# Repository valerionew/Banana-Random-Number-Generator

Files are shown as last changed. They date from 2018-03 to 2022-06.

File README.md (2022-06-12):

# Banana Random Number Generator
  


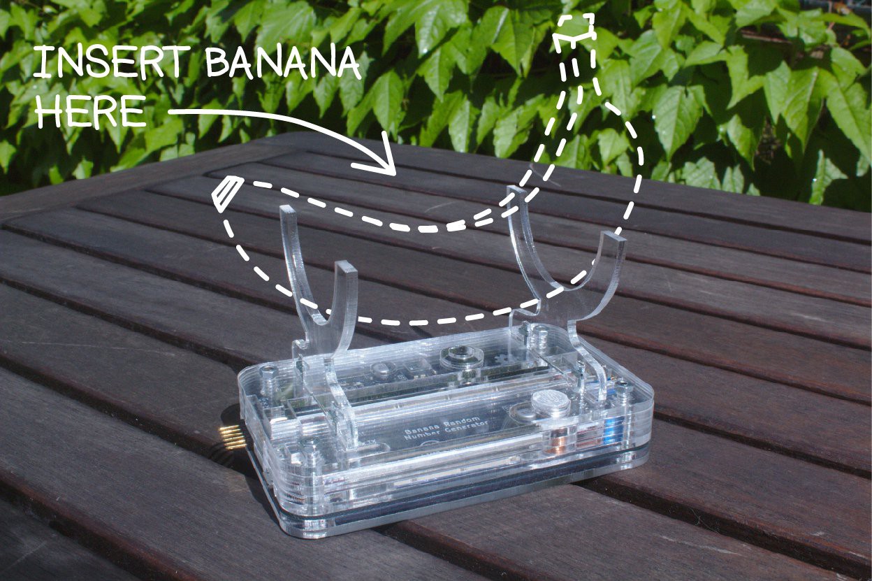
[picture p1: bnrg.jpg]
brng


## Project description 
An Arduino based true random number generator. Takes it's peculiar name from the potassium-40 present in bananas, used as radiation source for the random number generatation.  
  
_Disclaimer: the radioactivity from the bananas doesn't quite make the difference, the background radiation is more than enough to make the generator work. Potassium is definitely detected, some tests conducted with pure KCl and KOH showed a huge increase in the detector activity._

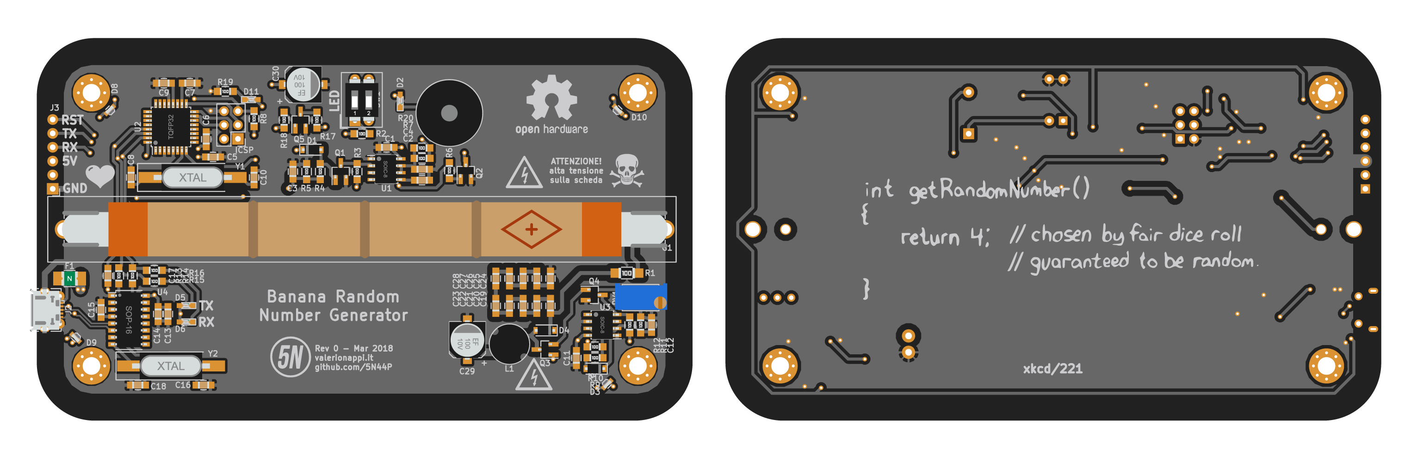
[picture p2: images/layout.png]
layout 1


1. [Project status](#project-status)  
1. [Hardware](#hardware)  
1. [Software](#software) 
1. [Enclosure](#enclosure) 

## Project status 
The current release is fully working. 
## Hardware 
The hardware is based around the popular ATMega328P and the STS-5 (a.k.a. CTC-5) Geiger-Müller tube.
## Software

As of this moment there are available two versions of the firmware:
- **minimal_test.c**: this version is fully compatible with the unmodified hardware. It uses the hardware interrupt INT0 and has proven to be unreliable when brought into an arduino environment due to interferences with the millis() function from the Wiring core. On it's own works with no problems. [Read more on this, in italian](https://www.valerionappi.it/chi-quadro/)
- **minimal_test_with capture.c**: this version and has proven to be much more reliable than the previous, since it captures the timer stamp via dedicated hardware and it's not subject to software delays. It's based on the timer capture function on PB0/ICP1 pin of the ATMega. This version needs a bodge wire between pin PD2 and pin PB0, as shown below:  

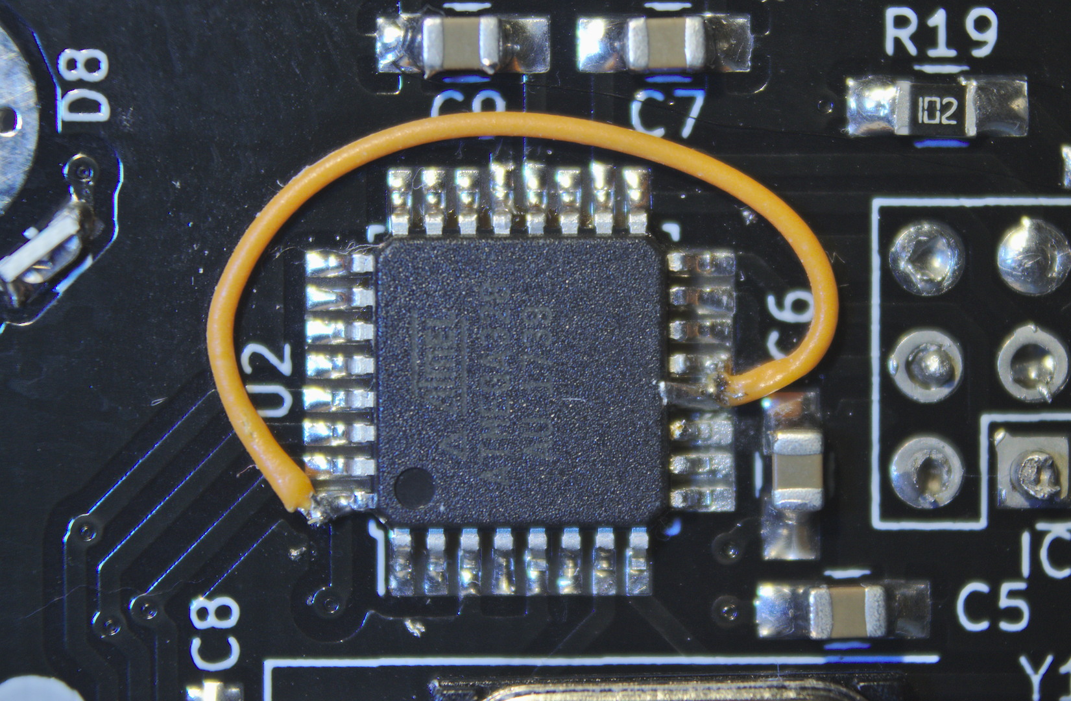
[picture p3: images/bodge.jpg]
mod


I'm currently working on an arduino version on the software, that will be published in this repo as soon as it gives consistent results.
In the future another version of the firmware which makes use of the hardware as a plain Geiger counter might be developed. Any help is welcome!
## Enclosure
The board is designed to fit in a laser cut acrylic enclosure to protect the user from the high voltage present onboard. 
The enclosure design files are included and licensed under [CC-BY-SA 4.0 license](http://creativecommons.org/licenses/by-sa/4.0/)

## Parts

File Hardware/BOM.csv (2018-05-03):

Id | Ref | Package | Qty | Value
1 | BZ1 | Buzzer_12x9.5RM7.6 | 1 | Buzzer
5 | C11 C1 C4 C5 C6 C13 C14 C15 C17 C19 C20 C21 C22 C23 C24 C25 C26 C27 C28 C2 C7 C3 C9 C31 | C_0805_HandSoldering | 24 | 100n 50V
35 | C29 C30 | CP_Elec_6.3x5.3 | 2 | 100u 6V
11 | C8 C10 C16 C18 C12 | C_0805_HandSoldering | 5 | 22p 10V
14 | D2 D11 | LED_0603_HandSoldering | 2 | LL-S194PBC-B4-1B
15 | D1 D3 D4 | D_SOD-123 | 3 | USL1M
6 | D5 D6 | LED_0603_HandSoldering | 2 | LL-S192UAC-1A
37 | D7 D8 D9 D10 | 0802_side_led | 4 | OSR50802C1E
16 | F1 | R_1210_HandSoldering | 1 | Polyfuse 500mA
17 | G1 | Geiger | 1 | STS-20 geiger + 2 KEYSTONE 3518P
18 | ICSP | Pin_Header_Straight_2x03_Pitch2.54mm | 1 | ISP
19 | J2 | USB_Micro-B_Molex-105017-0001 | 1 | MOLEX 105017 0001
4 | J3 | Pin_Header_Angled_1x06_Pitch2.54mm | 1 | Angled connector
20 | L1 | L_Radial_D7.2mm_P3.00mm_MuRATA_1700 | 1 | 15mH FASTRON 11PHC-153K-50
21 | Q1 Q2 Q4 Q5 | SOT-23_Handsoldering | 4 | BC847
22 | Q3 | SOT-23_Handsoldering | 1 | MMBTA42
23 | R1 | R_1206_HandSoldering | 1 | 10M YAGEO RC1206JR-0710ML
7 | R15 R16 R10 R13 R14 R19 | R_0805_HandSoldering | 6 | 1k
24 | R2 R6 R9 R17 R18 | R_0805_HandSoldering | 5 | 220
26 | R4 R5 R12 R11 R7 R20 R3 R8 | R_0805_HandSoldering | 8 | 100k
29 | RV1 | Potentiometer_Trimmer_Vishay_T73XW_Vertical | 1 | 100
30 | SW1 | SW_DIP_x2_W7.62mm_Slide | 1 | DIPTRONICS NDI-02H-V
31 | U1 U3 | SOIC-8_3.9x4.9mm_Pitch1.27mm | 2 | LM555N
32 | U2 | TQFP-32_7x7mm_Pitch0.8mm | 1 | ATMEGA328P-AU
33 | U4 | SOP-16_4.4x10.4mm_Pitch1.27mm | 1 | CH340G
36 | Y1 | Crystal_SMD_HC49-SD_HandSoldering | 1 | 16MHz LF XTAL003237
34 | Y2 | Crystal_SMD_HC49-SD_HandSoldering | 1 | 12MHz LF XTAL003210

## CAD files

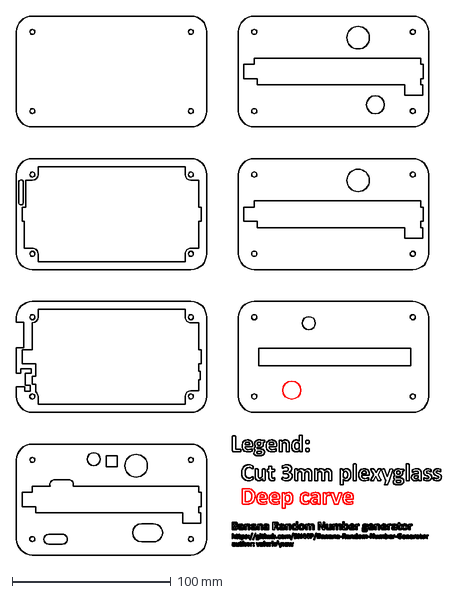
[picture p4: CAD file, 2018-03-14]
enclosure/enclosure.dxf
268.1 x 340.0 mm

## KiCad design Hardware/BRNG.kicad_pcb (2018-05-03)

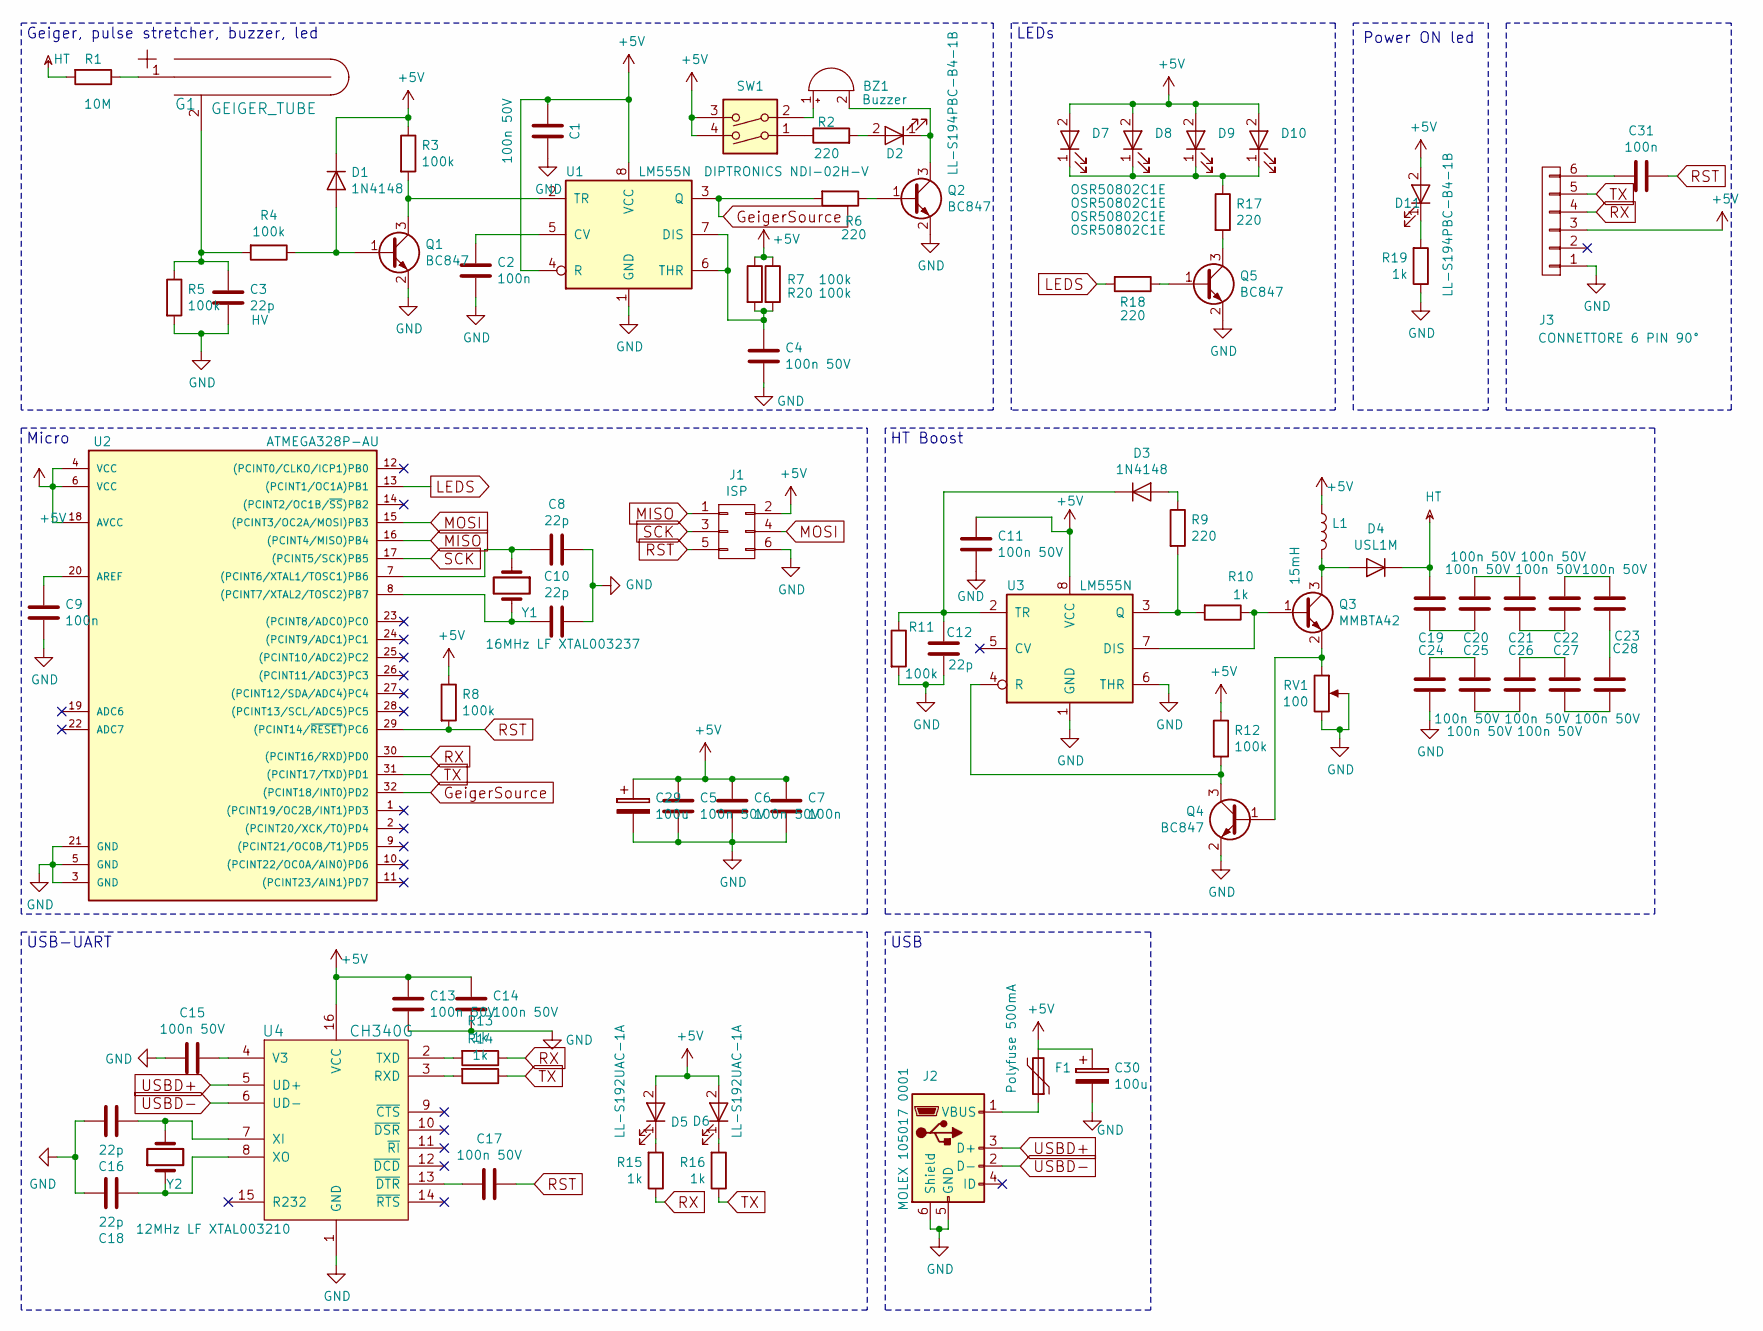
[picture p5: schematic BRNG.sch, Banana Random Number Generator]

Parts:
BZ1: Buzzer; Buzzer_12x9.5RM7.6
C1, C4, C5, C6, C11, C13, C14, C15, C17, C19, C20, C21, C22, C23, C24, C25, C26, C27, C28: 100n 50V; C_0805_HandSoldering
C2, C7, C9, C31: 100n; C_0805_HandSoldering
C3, C8, C10, C12, C16, C18: 22p; C_0805_HandSoldering
C29, C30: 100u; CP_Elec_6.3x5.3
D1, D3: 1N4148; D_SOD-123
D2, D11: LL-S194PBC-B4-1B; LED_0603_HandSoldering
D4: USL1M; D_SOD-123
D5, D6: LL-S192UAC-1A; LED_0603_HandSoldering
D7, D8, D9, D10: OSR50802C1E; 0802_side_led
F1: Polyfuse 500mA; R_1210_HandSoldering
G1: GEIGER_TUBE; Geiger
J1: ISP; Pin_Header_Straight_2x03_Pitch2.54mm
J2: MOLEX 105017 0001; USB_Micro-B_Molex-105017-0001
J3: CONNETTORE 6 PIN 90°; Pin_Header_Angled_1x06_Pitch2.54mm
L1: 15mH; L_Radial_D7.2mm_P3.00mm_MuRATA_1700
Q1, Q2, Q4, Q5: BC847; SOT-23_Handsoldering
Q3: MMBTA42; SOT-23_Handsoldering
R1: 10M; R_1206_HandSoldering
R2, R6, R9, R17, R18: 220; R_0805_HandSoldering
R3, R4, R5, R7, R8, R11, R12, R20: 100k; R_0805_HandSoldering
R10, R13, R14, R15, R16, R19: 1k; R_0805_HandSoldering
RV1: 100; Potentiometer_Trimmer_Vishay_T73XW_Vertical
SW1: DIPTRONICS NDI-02H-V; SW_DIP_x2_W7.62mm_Slide
U1, U3: LM555N; SOIC-8_3.9x4.9mm_Pitch1.27mm
U2: ATMEGA328P-AU; TQFP-32_7x7mm_Pitch0.8mm
U4: CH340G; SOP-16_4.4x10.4mm_Pitch1.27mm
Y1: 16MHz LF XTAL003237; Crystal_SMD_HC49-SD_HandSoldering
Y2: 12MHz LF XTAL003210; Crystal_SMD_HC49-SD_HandSoldering

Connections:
+5V: C1.2, C5.1, C6.1, C7.1, C11.1, C13.1, C14.1, C29.1, C30.1, D1.1 (K), D5.2 (A), D6.2 (A), D7.2 (A), D8.2 (A), D9.2 (A), D10.2 (A), D11.2 (A), F1.2, J1.2, J3.3, L1.1, R3.1, R7.1, R8.1, R12.1, R20.1, SW1.3, SW1.4, U1.4 (R), U1.8 (VCC), U2.4 (VCC), U2.6 (VCC), U2.18 (AVCC), U3.8 (VCC), U4.16 (VCC); also elsewhere on the board
GND: C1.1, C2.2, C3.2, C4.2, C5.2, C6.2, C7.2, C8.1, C9.2, C10.1, C11.2, C12.2, C13.2, C14.2, C15.2, C16.1, C18.1, C24.2, C29.2, C30.2, J1.6, J2.5 (GND), J2.6 (Shield), J3.1, Q1.2 (E), Q2.2 (E), Q4.2 (E), Q5.2 (E), R5.2, R11.2, R19.1, RV1.2, RV1.3, U1.1 (GND), U2.3 (GND), U2.5 (GND), U2.21 (GND), U3.1 (GND), U3.6 (THR), U4.1 (GND); also elsewhere on the board
GeigerSource: R6.2, U1.3 (Q), U2.32 ((PCINT18/INT0)PD2)
HT: C19.1, D4.1 (K), R1.2
LEDS: R18.2, U2.13 ((PCINT1/OC1A)PB1)
MISO: J1.1, U2.16 ((PCINT4/MISO)PB4); also elsewhere on the board
MOSI: J1.4, U2.15 ((PCINT3/OC2A/MOSI)PB3); also elsewhere on the board
unnamed: BZ1.1 (-), SW1.2
unnamed: BZ1.2 (+), D2.1 (K), Q2.3 (C)
unnamed: C2.1, U1.5 (CV)
unnamed: C3.1, G1.2, R4.2, R5.1
unnamed: C4.1, R7.2, R20.2, U1.6 (THR), U1.7 (DIS)
unnamed: C8.2, U2.7 ((PCINT6/XTAL1/TOSC1)PB6), Y1.1
unnamed: C9.1, U2.20 (AREF)
unnamed: C10.2, U2.8 ((PCINT7/XTAL2/TOSC2)PB7), Y1.2
unnamed: C12.1, D3.1 (K), R11.1, U3.2 (TR)
unnamed: C15.1, U4.4 (V3)
unnamed: C16.2, U4.7 (XI), Y2.2
unnamed: C17.2, U4.13 (~DTR)
unnamed: C18.2, U4.8 (XO), Y2.1
unnamed: C19.2, C20.2
unnamed: C20.1, C21.1
unnamed: C21.2, C22.2
unnamed: C22.1, C23.1
unnamed: C23.2, C28.1
unnamed: C24.1, C25.1
unnamed: C25.2, C26.2
unnamed: C26.1, C27.1
unnamed: C27.2, C28.2
unnamed: C31.1, J3.6
unnamed: D1.2 (A), Q1.1 (B), R4.1
unnamed: D2.2 (A), R2.2
unnamed: D3.2 (A), R9.1
unnamed: D4.2 (A), L1.2, Q3.3 (C)
unnamed: D5.1 (K), R15.2
unnamed: D6.1 (K), R16.2
unnamed: D7.1 (K), D8.1 (K), D9.1 (K), D10.1 (K), R17.1
unnamed: D11.1 (K), R19.2
unnamed: F1.1, J2.1 (VBUS)
unnamed: G1.1, R1.1
unnamed: Q1.3 (C), R3.2, U1.2 (TR)
unnamed: Q2.1 (B), R6.1
unnamed: Q3.1 (B), R10.1, U3.7 (DIS)
unnamed: Q3.2 (E), Q4.1 (B), RV1.1
unnamed: Q4.3 (C), R12.2, U3.4 (R)
unnamed: Q5.1 (B), R18.1
unnamed: Q5.3 (C), R17.2
unnamed: R2.1, SW1.1
unnamed: R9.2, R10.2, U3.3 (Q)
unnamed: R13.2, U4.2 (TXD)
unnamed: R14.2, U4.3 (RXD)
RST: C17.1, C31.2, J1.5, R8.2, U2.29 ((PCINT14/~RESET~)PC6); also elsewhere on the board
RX: J3.4, R13.1, R15.1, U2.30 ((PCINT16/RXD)PD0)
SCK: J1.3, U2.17 ((PCINT5/SCK)PB5); also elsewhere on the board
TX: J3.5, R14.1, R16.1, U2.31 ((PCINT17/TXD)PD1)
USBD+: J2.3 (D+), U4.5 (UD+)
USBD-: J2.2 (D-), U4.6 (UD-)

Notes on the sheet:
Micro
Geiger, pulse stretcher, buzzer, led
HT Boost
LEDs
Power ON led
USB-UART
USB

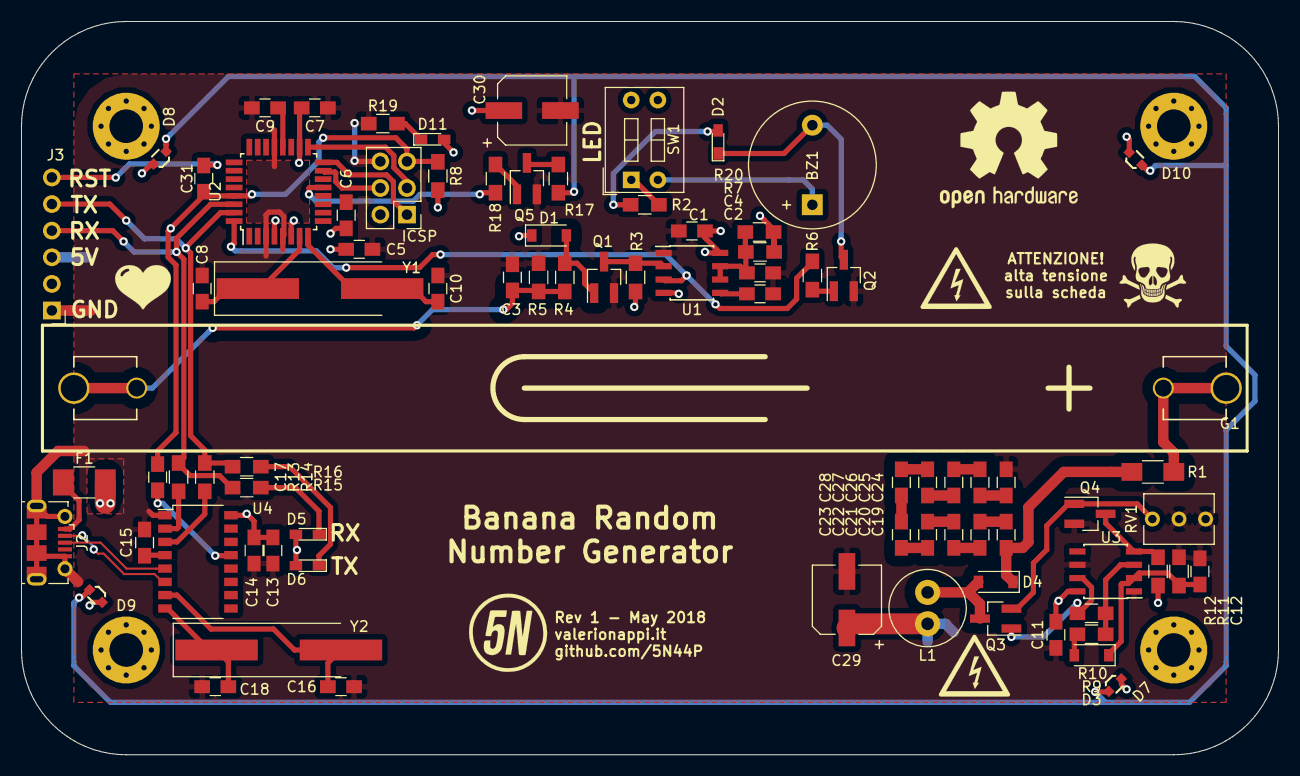
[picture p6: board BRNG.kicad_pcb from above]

Board: 2 copper layers, 120.0 x 70.0 mm, 82 parts (0 on the bottom side), 57 nets.

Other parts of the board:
ICSP: ISP; Pin_Header_Straight_2x03_Pitch2.54mm

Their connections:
+5V: ICSP.2; also elsewhere on the board
GND: ICSP.6; also elsewhere on the board
MISO: ICSP.1; also elsewhere on the board
MOSI: ICSP.4; also elsewhere on the board
RST: ICSP.5; also elsewhere on the board
SCK: ICSP.3; also elsewhere on the board

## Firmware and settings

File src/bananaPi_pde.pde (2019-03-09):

import processing.serial.*;

Serial bananaPort;  // Create object from Serial class

int x,y; // coordinates
float scalefactor;
String[] Serialports = Serial.list();
long inside, outside, total;

void setup() {
  
  if(Serialports.length > 0) // chech if there is at least one serial port
    bananaPort = new Serial(this, Serialports[0] , 9600); // choose the serial port of intrest, e.g. Serialports[1]
  printArray(Serial.list()); //print all serials, verify which number corresponds to yours
  
  // choose whatever resolution fits your screen.
  // it should be approximately 2x1 to display the interface correctly
  size(1500,750); 
  
  // scaling the 0-255 value from the serial into the appropriate format for the screen in use
  scalefactor = (height*0.7)/255;
 
   
  background(255); // white background
  colorMode(RGB,255); // RGB color mode
   
  // apply the transformation matrix for the point plot. 
  // remember that this function pushes a matrix, you have to pop it
  plotTransformation(); 
  
  strokeWeight(0.002); // set weak stroke weight
  ellipseMode(CENTER); // use center mode for the arcs
  fill(color(221, 254, 255)); // fill the shape with the right shade of blue
  arc(0,0,height*1.4,height*1.4,0,HALF_PI); // draw the circle quadrant
  
  noFill(); 
  strokeWeight(1); // heavier stroke
  rectMode(CORNER);
  rect(0,0,height*0.7,height*0.7); // draw the square
    
  noStroke(); // disable the stroke

  popMatrix(); // popping the plotTransformation() matrix
  
  
      fill(0); // black fill for the text
      textSize(width*0.05);
      text("Punti:", width*0.5, height*0.2); // total points label
      text("Interni:", width*0.5, height*0.35); // inside points label
      text("Esterni:", width*0.5, height*0.5); // outside points label
      textSize(width*0.075); // bigger text
      text("Pi:", width*0.5, height*0.8); // pi result label

  
}

void draw(){
  if (Serialports.length > 0){ // if there's at least one serial (not checking if it's assigned and initialized correctly, could be improved)
    
    if ( bananaPort.available() > 1) {  // if there's more than 1 byte available (we need two for each execution)
      x = bananaPort.read(); // first byte goes here
      y = bananaPort.read(); // second byte goes here
      total++; // increase total number
      plotTransformation(); // push transformation matrix for the plot
      if( x*x + y*y <= 255*255){ // if (x,y) belongs to a circle with raduis 255 the dot is inside
        fill(color(255,0,0));   // red dot
        inside++; // increase inside number
      }
      else{ // the point is outside the circle
        fill(color(0,0,255)); // blue dot
        outside++; // increase outside number
      }
      ellipse(x*scalefactor,y*scalefactor,5,5); // draw the dot, 5 pixel in size (not scalable, could be improved)
      popMatrix(); // pop the plot matrix
      
      println( x, y,inside,outside,total,(4.0*inside)/total); // DEBUG purpose only
      
      // blank the precedent values area
      fill(255); 
      rect(width*0.7,0,width*0.3,height);
      rect(width*0.6,height*0.65,width*0.4,height*0.35);
      
      // write the results since now
      fill(0);
      textSize(width*0.05);    
      text(int(total), width*0.7, height*0.2);
      text(int(inside), width*0.7, height*0.35);
      text(int(outside), width*0.7, height*0.5);
      textSize(width*0.075);
      text((4.0*inside)/total, width*0.6, height*0.8);
      
    }
  }
    
    
}

void plotTransformation(){
  pushMatrix(); // push a new matrix
  scale(1,-1); // invert Y axis
  translate(0,-height); // translate everything downwards
  translate(height*0.1,height*0.1); // give the plot a bit of margin
  // now point 0,0 is the origin of the plot
}

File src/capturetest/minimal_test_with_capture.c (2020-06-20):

/* 
 * This file is part of the Banana Random Number Generator project (https://github.com/valerionew/Banana-Random-Number-Generator).
 * Copyright (c) 2018 Mauro Mombelli.
 * 
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
 * You should have received a copy of the GNU General Public License 
 * along with this program. If not, see <http://www.gnu.org/licenses/>.
 */

#define F_CPU 16000000UL
#define BAUDRATE 9600        //The baudrate that we want to use
#define BAUD_PRESCALLER (((F_CPU / (BAUDRATE * 16UL))) - 1)    //The formula that does all the required math

#include <avr/io.h>
#include <avr/interrupt.h>
#include <stdint.h>
#include <stdbool.h>

void TIM1_init() {
	//set normal mode
	TCCR1A = 0;
	//no prescaler
	TCCR1B = (1 << CS10);
}

void USART_init(void){
	UBRR0H = BAUD_PRESCALLER >> 8;
	UBRR0L = BAUD_PRESCALLER;
	UCSR0B = (1<<TXEN0);
	UCSR0C = (1<<UCSZ00) | (1<<UCSZ01);
}

void TIMER1_CAPTURE_init (void){
	//capture flag rising enable
	TCCR1B |= (0 << ICES1);
	// enable capture interrupt
	TIMSK1 = (1<<ICIE1);
	DDRB |= (0<< PINB0);

}

void USART_send(const uint8_t data) {
	while(!(UCSR0A & (1 << UDRE0))) {
		//do nothing
		;
	}
	UDR0 = data;
}

uint8_t USART_receive(void) {
	while(!(UCSR0A & (1 << RXC0))) {
		//do nothing
		;
	}
	return UDR0;
}

bool USART_available(void) {
	return (UCSR0A & (1 << RXC0));
}

//important, 256 as we use the natural overflow to make a circular buffer
volatile uint8_t random[256];
uint8_t start = 0;
volatile uint8_t end = 0;
//volatile uint32_t counter = 0;

ISR(TIMER1_CAPT_vect){
    random[end++] = ICR1L; // low byte interrupt capture
    random[end++] = ICR1H; // high byte interrupt capture
}

int main() {
	DDRB |= (1<< PINB1); // set leds pin as output
	PORTB |= (1<< PINB1); // turn on leds

	TIM1_init();
	USART_init();
	TIMER1_CAPTURE_init();
	sei();
	while(true) {
		if (start != end) {
			USART_send(random[start++]);
		}
	}
}

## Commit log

2018-03-14 First hardware release
    [BRNG.kicad_pcb, BRNG.sch]
2018-03-22 minimal test
    Minimal test to try the quality of the random with minimal interference from interrupt.
2018-03-25 added led toggle for debug purposes
2018-03-28 removed led toggling
2018-05-02 Fixes #5
    [BRNG.kicad_pcb]
2018-05-02 added enclosure license
2018-05-03 Fixes #4
    [BRNG.kicad_pcb, BRNG.sch]
2018-05-03 added BOM
    [BOM.csv]
2018-05-03 changed BOM to use , instead of ;
    [BOM.csv]
2019-09-09 added control for onboard LEDs

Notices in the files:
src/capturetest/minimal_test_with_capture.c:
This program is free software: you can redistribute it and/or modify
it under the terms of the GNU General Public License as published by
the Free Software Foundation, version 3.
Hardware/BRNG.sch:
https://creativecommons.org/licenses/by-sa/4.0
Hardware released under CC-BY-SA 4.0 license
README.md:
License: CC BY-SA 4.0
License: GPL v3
